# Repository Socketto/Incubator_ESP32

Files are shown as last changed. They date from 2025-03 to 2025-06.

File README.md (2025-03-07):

### Project Overview

This project was born out of the desire to see if supermarket quail eggs are actually fertile (unlike chicken eggs). The goal was to explore the possibility of incubating quail eggs and monitor their development.
  
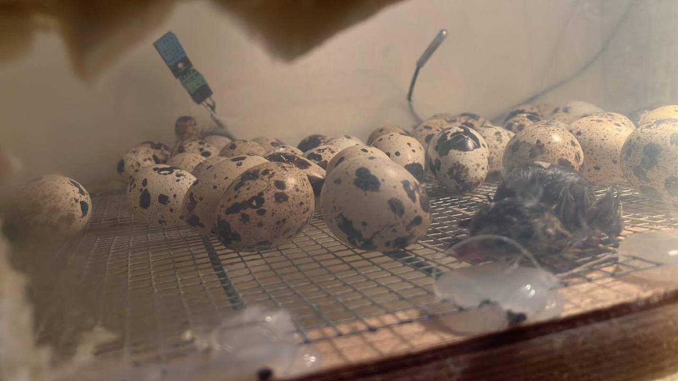
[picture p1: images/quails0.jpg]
quail
  

---

### The Incubator Design

To achieve this, I designed an **incubator for birds** using a thermally insulated plastic box. The setup is simple but effective for maintaining the right conditions for incubation.
  
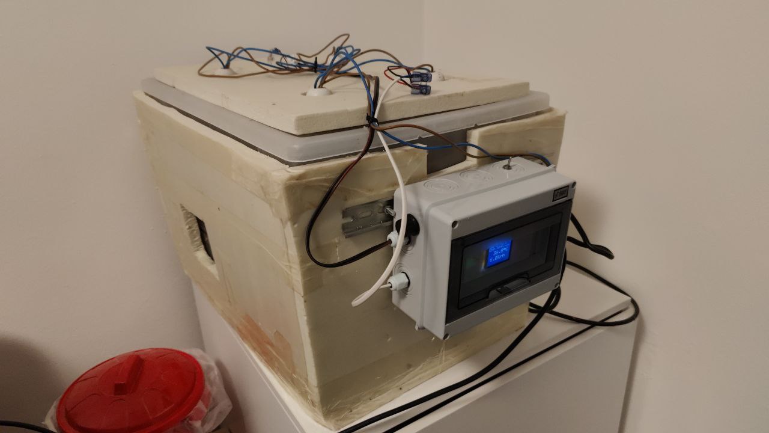
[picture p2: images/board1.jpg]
Incubator
  

---

### Temperature and Humidity Control

I managed the **temperature** and **humidity control** using a custom-designed board that features an **ESP32-WROOM** chip. This board was programmed using the **Arduino IDE**, providing full control over the incubator's conditions.

For heating, I used a **220V heater**, which I modulated using a **trimmer**. To maintain proper humidity inside, I used an **electric room humidifier**.

---

### User Interface and Remote Control

The board is equipped with a **color TFT graphical interface**, making it easy to monitor and control the incubator. Additionally, the incubator is controlled directly via a **Telegram bot** on your phone, allowing for remote management. 

For initial setup (WiFi credentials, Telegram token, and password), I added a feature that allows the board to switch to **Access Point (AP) mode**, enabling configuration through a minimal web server. These values are saved in the non-volatile memory of the ESP32, so they persist through future restarts.
  
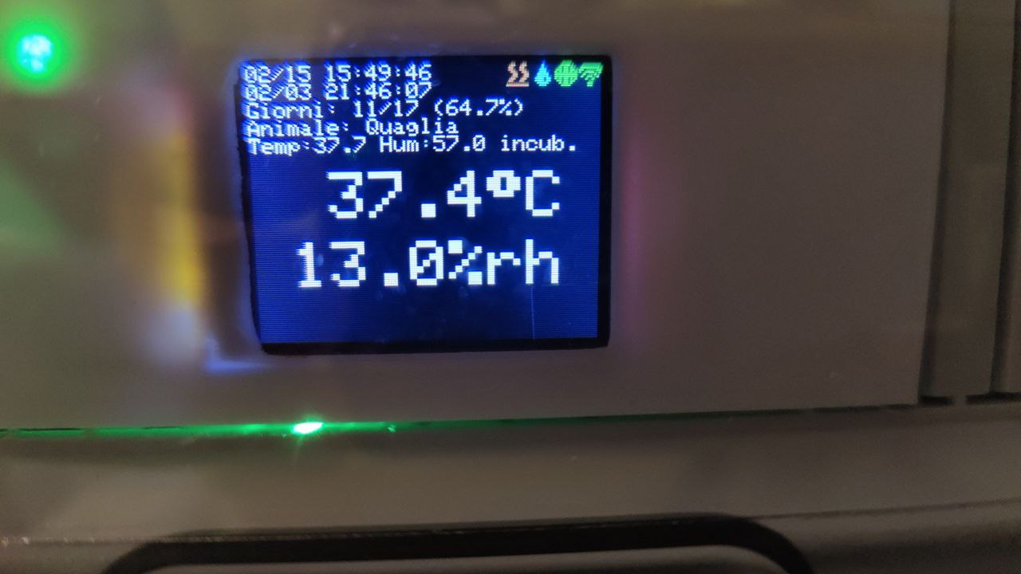
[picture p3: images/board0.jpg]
User interface
  

---

### Flexibility and Future Expansion

Currently, the software is configured to handle the **incubation periods**, **temperatures**, and **humidity** levels for chickens and quails. However, the system can easily be extended to accommodate other types of birds as well.
  
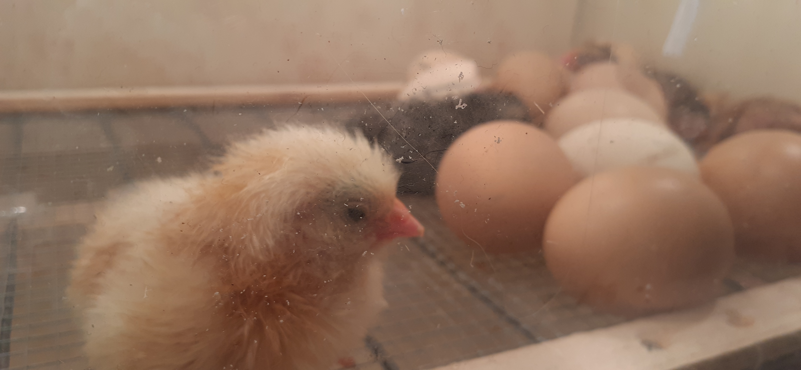
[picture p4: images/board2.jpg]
eggs
  

---

### Data Monitoring and Remote Supervision

The incubator's data can be communicated via **MQTT**, allowing for remote tracking of the incubation process from an external monitoring environment. I personally use **Node-RED** to monitor the data in real-time.

---

### Sharing the Experience

To make the project even more enjoyable, I set up a **live stream on Twitch** of the incubation process. This allows my friends to join in on the excitement and witness the first moments of life for the **❤️chicks❤️**.
  
[twitch channel](https://www.twitch.tv/socketto87)
  
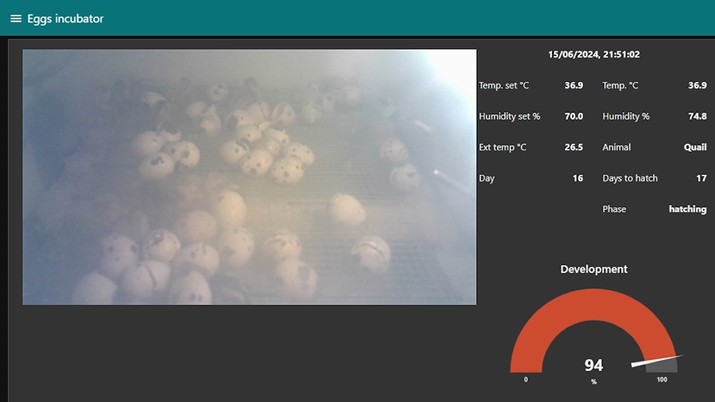
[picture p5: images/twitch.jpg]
twitch
  

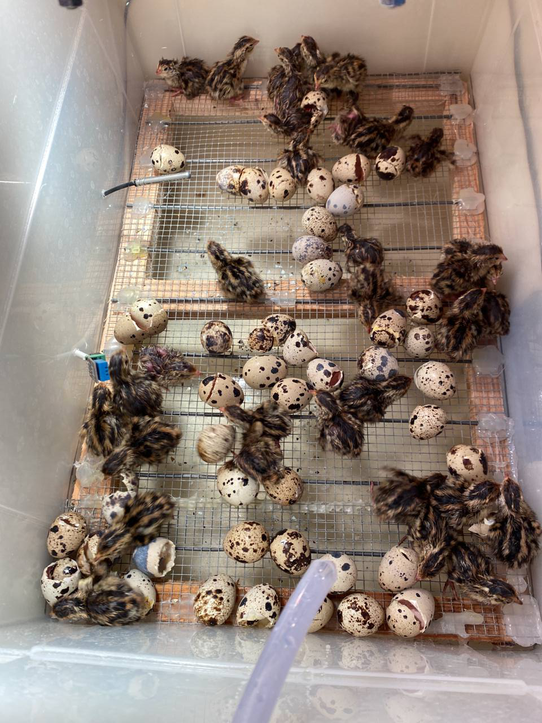
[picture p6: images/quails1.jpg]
quails


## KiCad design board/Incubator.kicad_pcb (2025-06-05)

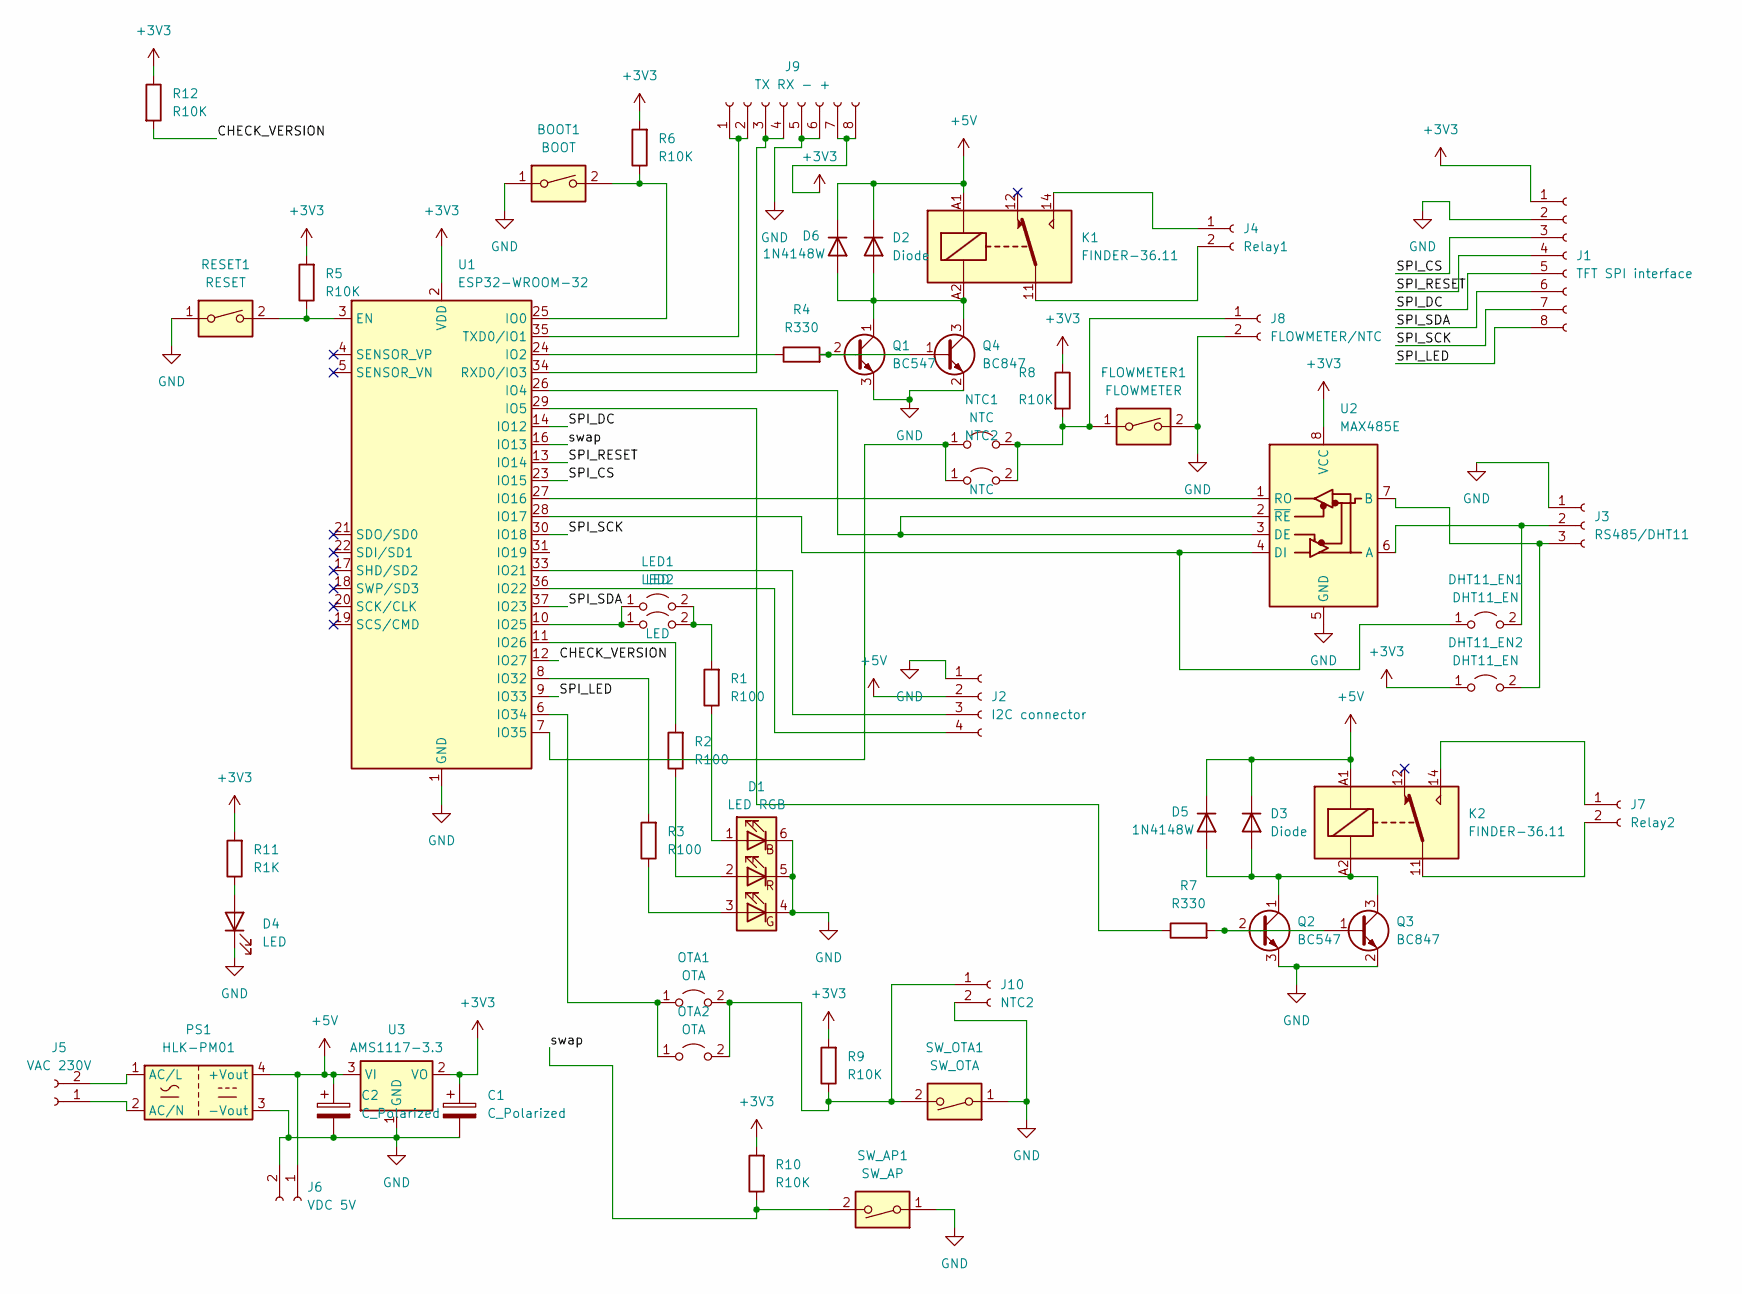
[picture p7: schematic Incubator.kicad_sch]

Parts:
BOOT1: BOOT; SW_PUSH_6mm_H4.3mm
C1, C2: C_Polarized; CP_Radial_D10.0mm_P5.00mm
D1: LED RGB; LED_RGB_5050-6
D2, D3: Diode; D_DO-35_SOD27_P10.16mm_Horizontal
D4: LED; LED_1206_3216Metric_Pad1.42x1.75mm_HandSolder
D5, D6: 1N4148W; D_SOD-123
DHT11_EN1, DHT11_EN2: DHT11_EN; SolderJumper-2_P1.3mm_Open_RoundedPad1.0x1.5mm
FLOWMETER1: FLOWMETER; SW_PUSH_6mm_H4.3mm
J1: TFT SPI interface; JST_XH_B8B-XH-AM_1x08_P2.50mm_Vertical
J2: I2C connector; JST_XH_B4B-XH-AM_1x04_P2.50mm_Vertical
J3: RS485/DHT11; PhoenixContact_MSTBA_2,5_3-G_1x03_P5.00mm_Horizontal
J4: Relay1; TerminalBlock_Altech_AK300-2_P5.00mm
J5: VAC 230V; TerminalBlock_Altech_AK300-2_P5.00mm
J6: VDC 5V; JST_XH_B2B-XH-A_1x02_P2.50mm_Vertical
J7: Relay2; TerminalBlock_Altech_AK300-2_P5.00mm
J8: FLOWMETER/NTC; TerminalBlock_Altech_AK300-2_P5.00mm
J9: TX RX - +; PinSocket_2x04_P2.54mm_Vertical
J10: NTC2; JST_XH_B2B-XH-A_1x02_P2.50mm_Vertical
K1, K2: FINDER-36.11; Relay_SPDT_Finder_36.11
LED1: LED; SolderJumper-2_P1.3mm_Open_RoundedPad1.0x1.5mm
LED2: LED; PinHeader_1x02_P2.54mm_Vertical
NTC1: NTC; PinHeader_1x02_P2.54mm_Vertical
NTC2: NTC; SolderJumper-2_P1.3mm_Open_RoundedPad1.0x1.5mm
OTA1: OTA; PinHeader_1x02_P2.54mm_Vertical
OTA2: OTA; SolderJumper-2_P1.3mm_Open_RoundedPad1.0x1.5mm
PS1: HLK-PM01; Converter_ACDC_HiLink_HLK-PMxx
Q1, Q2: BC547; TO-92_Inline
Q3, Q4: BC847; SOT-23
R1, R2, R3: R100; R_1206_3216Metric
R4, R7: R330; R_1206_3216Metric
R5, R6, R8, R9, R10, R12: R10K; R_1206_3216Metric
R11: R1K; R_1206_3216Metric
RESET1: RESET; SW_PUSH_6mm_H4.3mm
SW_AP1: SW_AP; SW_PUSH_6mm_H4.3mm
SW_OTA1: SW_OTA; SW_PUSH_6mm_H4.3mm
U1: ESP32-WROOM-32
U2: MAX485E; SO-8_3.9x4.9mm_P1.27mm
U3: AMS1117-3.3; SOT-223-3_TabPin2

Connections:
+3V3: C1.1, DHT11_EN2.1 (A), J1.1, J9.7, J9.8, R5.2, R6.2, R8.1, R9.2, R10.2, R11.2, R12.1, U1.2 (VDD), U2.8 (VCC), U3.2 (VO)
+5V: C2.1, D2.1 (K), D3.1 (K), D5.1 (K), D6.1 (K), J2.2, J6.1, K1.A1, K2.A1, PS1.4 (+Vout), U3.3 (VI)
/CHECK_VERSION: R12.2, U1.12 (IO27)
/SPI_CS: J1.3, U1.23 (IO15)
/SPI_DC: J1.5, U1.14 (IO12)
/SPI_LED: J1.8, U1.9 (IO33)
/SPI_RESET: J1.4, U1.13 (IO14)
/SPI_SCK: J1.7, U1.30 (IO18)
/SPI_SDA: J1.6, U1.37 (IO23)
/swap: R10.1, SW_AP1.2, U1.16 (IO13)
GND: BOOT1.1, C1.2, C2.2, D1.4 (GK), D1.5 (RK), D1.6 (BK), D4.1 (K), FLOWMETER1.2, J1.2, J2.1, J3.1, J6.2, J8.2, J9.5, J9.6, J10.2, PS1.3 (-Vout), Q1.3 (E), Q2.3 (E), Q3.2 (E), Q4.2 (E), RESET1.1, SW_AP1.1, SW_OTA1.1, U1.1 (GND), U1.15 (GND), U1.38 (GND), U1.39 (GND), U2.5 (GND), U3.1 (GND)
unnamed: D1.1 (BA), R1.1
unnamed: D1.3 (GA), R3.1
unnamed: D1.2 (RA), R2.1
unnamed: D2.2 (A), D6.2 (A), K1.A2, Q1.1 (C), Q4.3 (C)
unnamed: D3.2 (A), D5.2 (A), K2.A2, Q2.1 (C), Q3.3 (C)
unnamed: D4.2 (A), R11.1
unnamed: DHT11_EN1.1 (A), U1.28 (IO17), U2.4 (DI)
unnamed: DHT11_EN1.2 (B), J3.2, U2.6 (A)
unnamed: DHT11_EN2.2 (B), J3.3, U2.7 (B)
unnamed: J2.3, U1.33 (IO21)
unnamed: J2.4, U1.36 (IO22)
unnamed: J4.1, K1.14
unnamed: J4.2, K1.11
unnamed: J5.1, PS1.2 (AC/N)
unnamed: J5.2, PS1.1 (AC/L)
unnamed: J7.1, K2.14
unnamed: J7.2, K2.11
unnamed: FLOWMETER1.1, J8.1, NTC1.2 (B), NTC2.2 (B), R8.2
unnamed: J9.1, J9.2, U1.35 (TXD0/IO1)
unnamed: J9.3, J9.4, U1.34 (RXD0/IO3)
unnamed: J10.1, OTA1.2 (B), OTA2.2 (B), R9.1, SW_OTA1.2
unnamed: LED1.1 (A), LED2.1 (A), U1.10 (IO25)
unnamed: LED1.2 (B), LED2.2 (B), R1.2
unnamed: NTC1.1 (A), NTC2.1 (A), U1.7 (IO35)
unnamed: OTA1.1 (A), OTA2.1 (A), U1.6 (IO34)
unnamed: Q1.2 (B), Q4.1 (B), R4.2
unnamed: Q2.2 (B), Q3.1 (B), R7.2
unnamed: R5.1, RESET1.2, U1.3 (EN)
unnamed: BOOT1.2, R6.1, U1.25 (IO0)
unnamed: R4.1, U1.24 (IO2)
unnamed: U1.26 (IO4), U2.2 (~RE), U2.3 (DE)
unnamed: R7.1, U1.29 (IO5)
unnamed: U1.27 (IO16), U2.1 (RO)
unnamed: R2.2, U1.11 (IO26)
unnamed: R3.2, U1.8 (IO32)

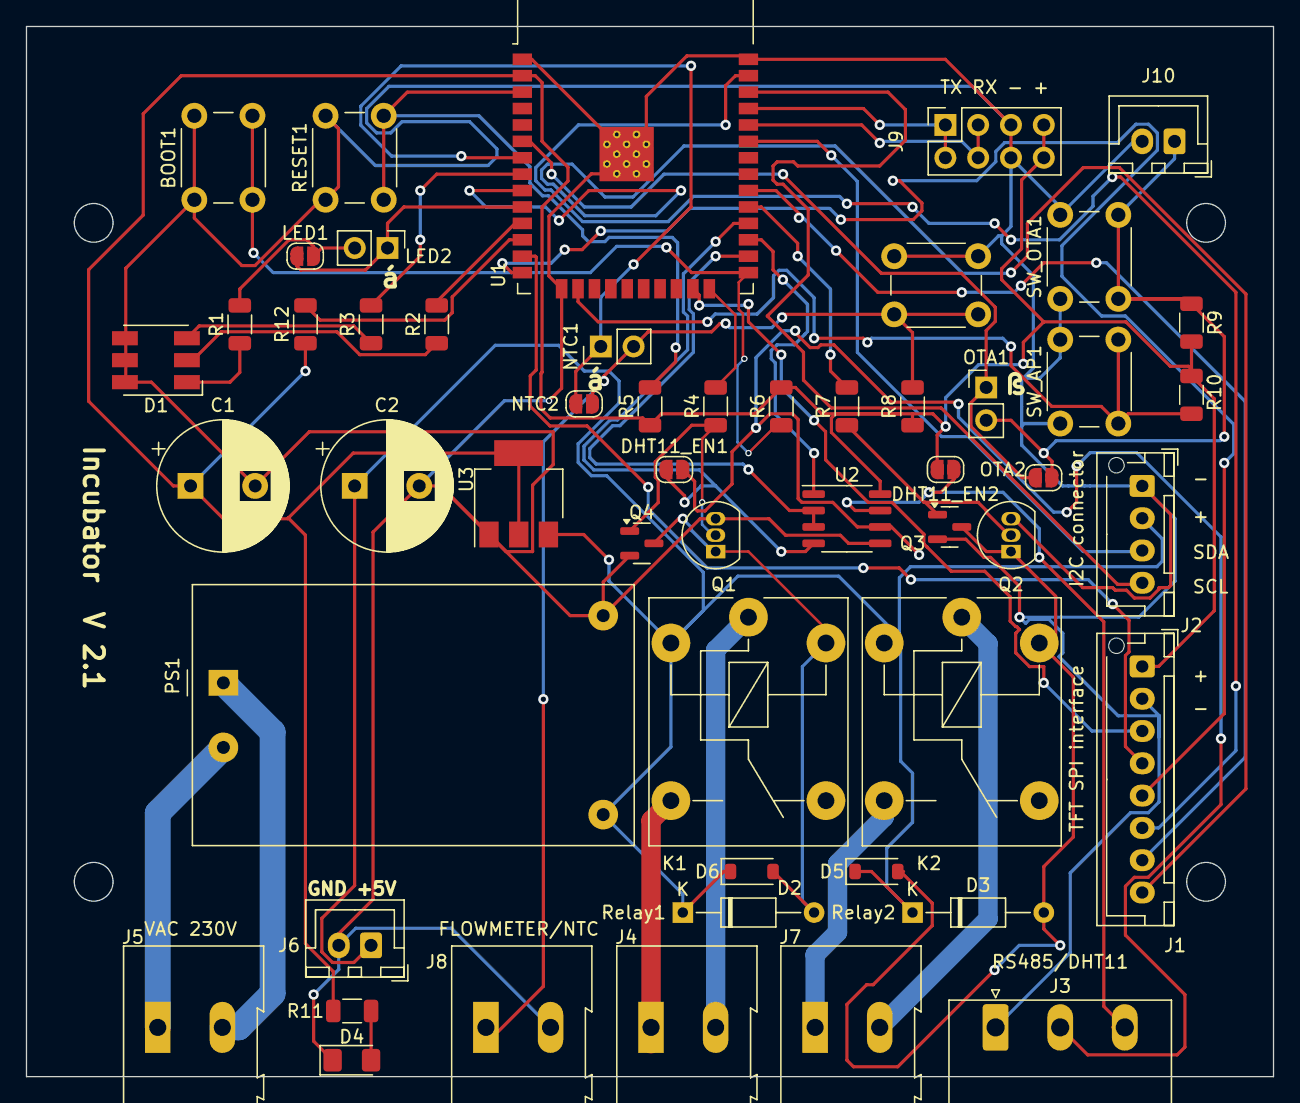
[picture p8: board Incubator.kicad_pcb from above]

Board: 2 copper layers, 96.5 x 81.3 mm, 53 parts (0 on the bottom side), 46 nets.

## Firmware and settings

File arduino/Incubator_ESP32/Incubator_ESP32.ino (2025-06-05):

#include <WiFi.h>
#include <Preferences.h>
#define NTC_SAMPLES 30

volatile int cycleTime = 10000; // 10 secondi
volatile int minOnTime = 3000;  // 2 secondi
volatile int customminOnTime = 0;
volatile int maxOnTime = 9000;  // 9 secondi

volatile double deltasetpoint = 0;
volatile double deltaTemperature = 0;
volatile long TimeUpdateMQTT = 60000;

bool DebugMutex = false;

SemaphoreHandle_t xMutex;  // Mutex per proteggere l'accesso
String ssid;
String ssidpassword;
String BOTtoken;
String AdminTelegram;
char stringWifi[200];
bool APMode = false;
char ChipID[50];

const char* WIFI_NAME = "WIFI_NAME";
const char* WIFI_PASSWORD = "WIFI_PASSWORD";
const char* TELEGRAM_BOT = "TELEGRAM_BOT";
const char* TELEGRAM_ADMIN = "TELEGRAM_ADMIN";
const char* URL_MQTT = "URL_MQTT";
const char* USERNAME_MQTT = "USERNAME_MQTT";
const char* PASSWORD_MQTT = "PASSWORD_MQTT";

int waitTemp = 0;
volatile int RebootRequested = -1;
int autoresetDisplay = 360;
int lastCheckReboot;
int animaleint = 0;
char Animale[200];


char StartIncubata[200];

bool AlarmsManagement = true;
int StepIncubata = 0;
int giornipassatiint = 0;
int giornipassatiintold = 0;
int giornitotaliint = 0;
char GiorniPassati[200];
char humstr[200];

char StartDay[200];
char settingsstr[200];
unsigned long lastreadntc;
char lcdStringTemp1[200];
char lcdStringTemp2[200];
int SecondsSetupWifi = 30;
bool first_read_time = true;
bool ErrorHumidity = true;
double Arraytemp[NTC_SAMPLES];
int indexarratemp = 0;
bool Temp1Ready = false;

float desiredH = 70;
double tempext = 0, tempextt = 0, desiredT = 37.0;
double histT = 0.1, histH = 10;

bool Reset = false;
Preferences preferences;
Preferences preferences_command;

volatile float humidity;
unsigned long lastCheckLocalTime = 0;
unsigned long lastTemperatureMQTT = 0;
unsigned long lastCheckAlarms = 0;
unsigned int testpercentage = 0;
long mainLightsForce = 0;
struct tm timeinfo;
struct tm startTime;
bool heater = false, humidifier = false;

const char* ntpServer = "pool.ntp.org";
const long gmtOffset_sec = 3600;
const int daylightOffset_sec = 3600;
// Latitude and Longitude for Piove di Sacco, Italy
float latitude = 45.2991;
float longitude = 12.0468;
float PercentageGiorniPassati = 0;

// Function to check if Daylight Saving Time (DST) is in effect
bool isDST(int day, int month, int dow) {
  if (month < 3 || month > 10) return false;
  if (month > 3 && month < 10) return true;

  int previousSunday = day - dow;

  if (month == 3) return previousSunday >= 25;
  if (month == 10) return previousSunday < 25;

  return false;
}

void StartAPMode() {
  Cian(true);
  delay(2000);
  WiFi.mode(WIFI_AP);
  sprintf(stringWifi, "%s", ChipID);
  WiFi.softAP(stringWifi, "12345679");
  sprintf(lcdStringTemp2, "%s", ChipID);
  TFT_log("WIFI", lcdStringTemp2, 3);
  TFT_log("PASSWORD", "12345679", 3);
  delay(5000);
  APMode = true;
  preferences.putUInt("APMode", 0);
  setupAP();
}

void saveTimeInfo() {
  preferences.begin("time-info", false);
  preferences.putInt("tm_sec", timeinfo.tm_sec);
  preferences.putInt("tm_min", timeinfo.tm_min);
  preferences.putInt("tm_hour", timeinfo.tm_hour);
  preferences.putInt("tm_mday", timeinfo.tm_mday);
  preferences.putInt("tm_mon", timeinfo.tm_mon);
  preferences.putInt("tm_year", timeinfo.tm_year);
  preferences.putInt("tm_wday", timeinfo.tm_wday);
  preferences.putInt("tm_yday", timeinfo.tm_yday);
  preferences.putInt("tm_isdst", timeinfo.tm_isdst);
  preferences.end();
}
void readTimeInfo() {
  preferences.begin("time-info", true);
  startTime.tm_sec = preferences.getInt("tm_sec", 0);
  startTime.tm_min = preferences.getInt("tm_min", 0);
  startTime.tm_hour = preferences.getInt("tm_hour", 0);
  startTime.tm_mday = preferences.getInt("tm_mday", 1);
  startTime.tm_mon = preferences.getInt("tm_mon", 0);
  startTime.tm_year = preferences.getInt("tm_year", 70);
  startTime.tm_wday = preferences.getInt("tm_wday", 0);
  startTime.tm_yday = preferences.getInt("tm_yday", 0);
  startTime.tm_isdst = preferences.getInt("tm_isdst", -1);
  preferences.end();
}

void CheckLocalTime() {
  if (!getLocalTime(&timeinfo)) {
    TFT_log("Time", "Failed to obtain time", 2);
    Serial.println("Failed to obtain time");
    Red(true);
    return;
  } else {
    strftime(lcdStringTemp1, sizeof(lcdStringTemp1), "%m/%d %H:%M:%S", &timeinfo);
    if (Reset) {
      saveTimeInfo();
      Reset = false;
    }

    readTimeInfo();
    strftime(StartDay, sizeof(StartDay), "%m/%d %H:%M:%S", &startTime);

    if (first_read_time) {
      first_read_time = false;
      TFT_log("Time", lcdStringTemp1, 0);
    }

    UpdateTime(lcdStringTemp1);
  }
  //Serial.println(&timeinfo, "%A, %B %d %Y %H:%M:%S");
}


void setup() {
  Serial.begin(115200);
  xMutex = xSemaphoreCreateMutex();  // Creazione del mutex
  strcpy(ChipID, Network.macAddress().c_str());
  
  struct tm timeInfo;
  if(preferences_command.begin("incu1"))
  {
    animaleint = preferences_command.getInt("Animale", 0);
    if (animaleint == 2) {
      AlarmsManagement = false;
    }

    deltaTemperature = (double)preferences_command.getInt("deltaTe", 0.0)/100;
    Serial.println(deltaTemperature);
    deltasetpoint = (double)preferences_command.getInt("deltase", 0)/100;
    Serial.println(deltasetpoint);
    TimeUpdateMQTT = preferences_command.getLong("TimQTT", 60000);
    Serial.println(TimeUpdateMQTT);
    maxOnTime = preferences_command.getInt("maxOnTime", 9000);
    Serial.println(maxOnTime);
    minOnTime = preferences_command.getInt("minOnTime", 3000);
    Serial.println(minOnTime);
    cycleTime = preferences_command.getInt("cycleTime", 10000);
    Serial.println(cycleTime);
    desiredT = preferences_command.getFloat("desiredT", 37);
    Serial.println(desiredT);
    desiredH = preferences_command.getFloat("desiredH", 70);
    Serial.println(desiredH);
    customminOnTime = preferences_command.getInt("customm", 0);
    Serial.println(customminOnTime);
    preferences_command.end();
  }
  else
  {
    Serial.println("ERROR (preferences_command.begin)");
  }
  initHeaterTask();
  Serial.println("setupIO()");
  setupIO();
  Yellow(false);
  delay(200);
  Serial.println("SetupTFT()");
  SetupTFT();
  TFT_log_init();
  Serial.println("TFT_log_init");
  delay(200);
  WiFi.mode(WIFI_STA);
  Serial.println("WiFi.mode(WIFI_STA)");
  preferences.begin("my-app", true);
  ssid = preferences.getString("SSID", "");
  ssidpassword = preferences.getString("SSIDPSW", "");
    if (ssid == "" || ssidpassword == "") {
      TFT_log("ERROR WIFI", "NOT SETTED!", 2);
      ssid = "TEST";
      ssidpassword = "123456789";
      SecondsSetupWifi = 0;
      delay(5000);
    }
  WiFi.begin(ssid, ssidpassword);
  Serial.print("Connecting to WiFi: ");
  ssid.toCharArray(stringWifi, ssid.length() + 1);
  TFT_log("WIFI", stringWifi, 1);
  TFT_log_append("WAIT seconds ", 30, true);
  Serial.println(ssid);
  Red(true);
  while (WiFi.status() != WL_CONNECTED && SecondsSetupWifi > 0) {
    Serial.print('.');
    TFT_log_append(".", 65535, false);
    SecondsSetupWifi--;
    delay(1000);
  }
  if(SecondsSetupWifi == 0)
  {
    StartAPMode();
    return;
  }
  else
  {
    setupAP();
  }
  BOTtoken = preferences.getString("TELEGRAM_BOT", "");
  Serial.println(BOTtoken);
  AdminTelegram = preferences.getString("TELEGRAM_ADMIN", "");
  Serial.println(AdminTelegram);
  preferences.end();
  Green(true);
  Serial.println("TelegramSetup()");
  TelegramSetup();
  delay(200);
  MQTT_setServer();
  while (MQTT_reconnect() == false) {
    delay(1000);
  }
  //init and get the time
  configTime(gmtOffset_sec, daylightOffset_sec, ntpServer);
  CheckLocalTime();
  InitDashboard();
  Serial.println("TimeTask...");
  xTaskCreate(
    TelegramTask,   /* Task function. */
    "TelegramTask", /* String with name of task. */
    20000,          /* Stack size in bytes. */
    NULL,           /* Parameter passed as input of the task */
    0,              /* Priority of the task. */
    NULL);          /* Task handle. */

  setupDHT();
}

void TelegramTask(void* pvParameters) {
  while (true) {
    TelegramLoop();
    vTaskDelay(pdMS_TO_TICKS(200));  // Usa FreeRTOS per ritardare il task
  }
}

tm copyTMStruct(tm* source) {
  tm destination;
  destination.tm_sec = source->tm_sec;
  destination.tm_min = source->tm_min;
  destination.tm_hour = source->tm_hour;
  destination.tm_mday = source->tm_mday;
  destination.tm_mon = source->tm_mon;
  destination.tm_year = source->tm_year;
  destination.tm_wday = source->tm_wday;
  destination.tm_yday = source->tm_yday;
  destination.tm_isdst = source->tm_isdst;

  return destination;
}
// Funzione per convertire una struttura tm in epoch time
time_t tmToEpochTime(tm& date) {
  tm tempdatetime = copyTMStruct(&date);
  return mktime(&tempdatetime);
}

// Funzione per calcolare la differenza in giorni tra due date
int differenceInDays(tm& startDate, tm& endDate) {
  time_t startEpoch = tmToEpochTime(startDate);
  time_t endEpoch = tmToEpochTime(endDate);
  double differenceInSeconds = difftime(endEpoch, startEpoch);
  int differenceInDaysi = (int)(differenceInSeconds / (60 * 60 * 24));
  return differenceInDaysi;
}

void loop() {

  if(APMode)
  {
    checkAP();
    return;
  }
  else
  {
    checkAP();
  }

  if (millis() > lastCheckReboot + 1000) {  //1 minuto
    lastCheckReboot = millis();
    if (xSemaphoreTake(xMutex, portMAX_DELAY)) {
      if (DebugMutex) {
        Serial.println("Mutex RebootRequested");
      }
      if (RebootRequested >= 0) {
        RebootRequested--;
      }
      if (RebootRequested == 0) {
        ESP.restart();
      }
      if (DebugMutex) {
        Serial.println("Mutex released");
      } 

      xSemaphoreGive(xMutex);
    }
  }



  if (WiFi.status() != WL_CONNECTED) {
    UpdateWifiStatus(0);
    UpdateServerStatus(0);
    Red(true);
    if (WiFi.status() != WL_CONNECTED) {
      Serial.print('.');
      TFT_log_append(".", 65535, false);
      delay(1000);
      SecondsSetupWifi--;
      if (SecondsSetupWifi <= 0) {
        SecondsSetupWifi = 30;
        WiFi.disconnect();
        WiFi.reconnect();
      }
    }
    TFT_log_append("", 65535, true);
  } else {
    UpdateWifiStatus(2);
    Green(true);
    if (MQTT_reconnect()) {
      MQTT_loop();
	  if (xSemaphoreTake(xMutex, portMAX_DELAY)) {   
		if (DebugMutex) {
		  Serial.println("Mutex MQTT_Wifi_Status");
		}
		MQTT_Wifi_Status(WiFi.RSSI());
		xSemaphoreGive(xMutex); 
		if (DebugMutex) {
		  Serial.println("Mutex released");
		}
	  }
    }
  }

  if (xSemaphoreTake(xMutex, portMAX_DELAY)) {
    if (DebugMutex) {
      Serial.println("Mutex loop");
    }
    switch (animaleint) {
      case 0:
        giornitotaliint = 21;
        strcpy(Animale, "Animale: Gallina");
        if (giornipassatiint <= 18) {
          StepIncubata = 1;
        } else {
          if (StepIncubata < 2)
            StepIncubata = 2;
        }
        break;
      case 1:
        giornitotaliint = 17;
        strcpy(Animale, "Animale: Quaglia");
        if (giornipassatiint <= 15) {
          StepIncubata = 1;
        } else {
          if (StepIncubata < 2)
            StepIncubata = 2;
        }
        break;
      case 2:
        giornitotaliint = 365;
        strcpy(Animale, "Animale: NO");
        StepIncubata = 100;
        break;
    }
    switch (StepIncubata) {
      case 1:  //incubazione
        desiredH = 57;
        desiredT = 37.7;
        histT = 0.1;
        histH = 10;
        sprintf(settingsstr, "Temp:%2.1f Hum:%2.1f incub.", desiredT, desiredH);
        break;
      case 2:  //schiusa
        desiredH = 70;
        desiredT = 36.9;
        histT = 0.1;
        histH = 10;
        sendSchiusa();
        StepIncubata = 3;
        break;
      case 3:  //schiusa
        sprintf(settingsstr, "Temp:%2.1f Hum:%2.1f schiusa", desiredT, desiredH);
        break;
      default:
        sprintf(settingsstr, "Temp:%2.1f Hum:%2.1f ----", desiredT, desiredH);
        break;
    }

    giornipassatiint = differenceInDays(startTime, timeinfo);

    PercentageGiorniPassati = (float)((float)(giornipassatiint * 100) / (float)(giornitotaliint));
    sprintf(GiorniPassati, "Giorni: %d/%d (%2.1f%%)", giornipassatiint, giornitotaliint, PercentageGiorniPassati);

    if (millis() > lastTemperatureMQTT + TimeUpdateMQTT) {  //60 sec
      lastTemperatureMQTT = millis();
      MQTT_Publish();
      if(autoresetDisplay > 0) //
      {
        autoresetDisplay--;
        if(autoresetDisplay == 0)
        {
          autoresetDisplay = 30; //30 mim
          ResetTFT();
        }
      }
      if(customminOnTime == 0)
      {
          if(readtempEXT() <= 15)
          {
            minOnTime = 4000;
          }
          if(readtempEXT() > 15)
          {
            minOnTime = 3000;
          }
          if(readtempEXT() > 20)
          {
            minOnTime = 2000;
          }
          if(readtempEXT() > 25)
          {
            minOnTime = 1000;
          }
      }
    }

    if (millis() > lastreadntc + 100) {
      lastreadntc = millis();
      Arraytemp[indexarratemp] = readtemp();
      indexarratemp++;
      if (indexarratemp >= NTC_SAMPLES) {
        indexarratemp = 0;
        Temp1Ready = true;
      } else {
        waitTemp = (int)((double)((double)indexarratemp / (double)NTC_SAMPLES) * 100);
      }
      if (Temp1Ready) {
        tempextt = 0;
        for (int o = 0; o < NTC_SAMPLES; o++) {
          tempextt = tempextt + Arraytemp[o];
        }
        tempext = tempextt / NTC_SAMPLES;
      }
    }
    Updaterows();
    /*if (Temp1Ready) {
      if (tempext > desiredT + histT)
        heater = false;
      if (tempext < desiredT - histT)
        heater = true;
    }*/
    humidity = loopDHT();
    if (humidity >= 0) {
      ErrorHumidity = false;
      sprintf(humstr, " %2.1f%%rh", humidity);
      if (humidity > desiredH + histH)
        humidifier = false;
      if (humidity < desiredH - histH)
        humidifier = true;
    } else {
      ErrorHumidity = true;
    }
    CheckLocalTime();
    //Relay1(heater);
    Relay2(humidifier);
    if (DebugMutex) {
      Serial.println("Mutex released");
    }
    xSemaphoreGive(xMutex);
  }
}

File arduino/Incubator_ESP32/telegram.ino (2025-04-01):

#include <WiFiClientSecure.h>
#include <UniversalTelegramBot.h>  // Universal Telegram Bot Library written by Brian Lough: https://github.com/witnessmenow/Universal-Arduino-Telegram-Bot
#include <ArduinoJson.h>
#include <Preferences.h>
#include <HTTPClient.h>
#include <WiFi.h>

UniversalTelegramBot* bot;  // Pointer declaration
// Initialize Telegram BOT
char MessageAuthomatic[400];

bool userAuthorized(String value) {
  if (AdminTelegram == value) {
    return true;  // value found
  }
  return false;  // value not found
}


float extractFloat(String input) {
  bool foundDigit = false;
  String numStr = "";

  for (int i = 0; i < input.length(); i++) {
    char c = input[i];


    if (isdigit(c) || c == '.') {
      numStr += c;
      foundDigit = true;
    }

    else if (c == '-' && !foundDigit && i + 1 < input.length() && isdigit(input[i + 1])) {
      numStr += c;
    }

    else if (foundDigit) {
      break;
    }
  }

  return numStr.length() > 0 ? numStr.toFloat() : 0.0;
}

char messaget[400];
WiFiClientSecure clientt;

// Checks for new messages every 1 second.
int botRequestDelay = 1000;
unsigned long lastTimeBotRan;


// Handle what happens when you receive new messages
void handleNewMessages(int numNewMessages) {
  Serial.println("handleNewMessages");
  Serial.println(String(numNewMessages));

  for (int i = 0; i < numNewMessages; i++) {
    // Chat id of the requester
    String chat_id = String(bot->messages[i].chat_id);
    if (userAuthorized(chat_id) == false) {
      bot->sendMessage(chat_id, "Unauthorized user", "");
      continue;
    }

    // Print the received message
    String text = bot->messages[i].text;
    Serial.println(text);

    String from_name = bot->messages[i].from_name;

    if (text == "/start") {
      String welcome = "Welcome";
      bot->sendMessage(chat_id, welcome, "");
    }

    if (text == "/status") {
      if (Temp1Ready) {
        sprintf(messaget, "Wifi signal: %d%%\n%s\n%s\nTemperature: %2.1f°C\nHumidity: %2.1f%%\nStart: %s\nIP: http://%s", testpercentage, Animale, GiorniPassati, tempext, humidity, StartIncubata, WiFi.localIP().toString());
        bot->sendMessage(chat_id, messaget, "");
        sprintf(messaget, "cycle-time %i\nmin-on-time %i\ncustomminOnTime %i\nmax-on-time %i\nset-delta-set-point %2.2f\nupdate-mqtt %lu\nset-delta-temp %2.2f", cycleTime, minOnTime, customminOnTime, maxOnTime, deltasetpoint, TimeUpdateMQTT, deltaTemperature);
        bot->sendMessage(chat_id, messaget, "");
        MQTT_Publish();
      } else {
        sprintf(messaget, "Wifi signal: %d%%", testpercentage);
        bot->sendMessage(chat_id, messaget, "");
      }
    }

    if (text == "/gallina") {
      preferences_command.begin("incu1", false);
      preferences_command.putInt("Animale", 0);
      animaleint = 0;
      preferences_command.end();
      bot->sendMessage(chat_id, "Ok", "");
      AlarmsManagement = true;
    }

    if (text == "/quaglia") {
      preferences_command.begin("incu1", false);
      preferences_command.putInt("Animale", 1);
      animaleint = 1;
      preferences_command.end();
      bot->sendMessage(chat_id, "Ok", "");
      AlarmsManagement = true;
    }

    if (text == "/noanimal") {
      preferences_command.begin("incu1", false);
      preferences_command.putInt("Animale", 2);
      animaleint = 2;
      preferences_command.end();
      bot->sendMessage(chat_id, "Ok", "");
      AlarmsManagement = false;
    }

    if (text == "reset-display") {
      ResetTFT();
      bot->sendMessage(chat_id, "Ok", "");
    }

    if (text == "soft-reset-tft") {
      SoftResetTFT();
      bot->sendMessage(chat_id, "Ok", "");
    }


    if (text == "/reset") {
      Reset = true;
      bot->sendMessage(chat_id, "Ok", "");
    }

    if (text == "/reboot") {
      bot->sendMessage(chat_id, "Ok", "");
      RebootRequested = 7;
    }

    if (text == "comandi") {
      bot->sendMessage(chat_id, "reset-display\nsoft-reset-tft\nset-temp 60\ncycle-time 10000\nmin-on-time 3000\ndefault-min-on-time\nmax-on-time 9000\nupdate-mqtt 60000\nset-delta-set-point 1.5\nset-delta-temp 1.5\nset-hum 50", "");
    }

    if (text.startsWith("set-temp ")) {
      desiredT = extractFloat(text);
      preferences_command.begin("incu1", false);
      preferences_command.putFloat("desiredT", desiredT);
      preferences_command.end();
      bot->sendMessage(chat_id, "Ok", "");
    }
    if (text.startsWith("cycle-time ")) {
      cycleTime = (int)extractFloat(text);
      preferences_command.begin("incu1", false);
      preferences_command.putInt("cycleTime", cycleTime);
      preferences_command.end();
      bot->sendMessage(chat_id, "Ok", "");
    }
    if (text.startsWith("min-on-time ")) {
      minOnTime = (int)extractFloat(text);
      preferences_command.begin("incu1", false);
      preferences_command.putInt("minOnTime", minOnTime);
      preferences_command.end();
      customminOnTime = minOnTime;
      preferences_command.begin("incu1", false);
      preferences_command.putInt("customminOnTime", customminOnTime);
      preferences_command.end();
      bot->sendMessage(chat_id, "Ok", "");
    }
    if (text == "default-min-on-time") {
      customminOnTime = 0;
      preferences_command.begin("incu1", false);
      preferences_command.putInt("customm", customminOnTime);
      preferences_command.end();
      bot->sendMessage(chat_id, "Ok", "");
    }
    if (text.startsWith("max-on-time ")) {
      maxOnTime = (int)extractFloat(text);
      preferences_command.begin("incu1", false);
      preferences_command.putInt("maxOnTime", maxOnTime);
      preferences_command.end();
      bot->sendMessage(chat_id, "Ok", "");
    }
    if (text.startsWith("update-mqtt ")) {
      TimeUpdateMQTT = (long)extractFloat(text);
      preferences_command.begin("incu1", false);
      preferences_command.putLong("TimQTT", TimeUpdateMQTT);
      preferences_command.end();
      bot->sendMessage(chat_id, "Ok", "");
    }
    if (text.startsWith("set-delta-set-point ")) {
      deltasetpoint = extractFloat(text);
      preferences_command.begin("incu1", false);
      preferences_command.putInt("deltase", (int)(deltasetpoint * 100));
      preferences_command.end();
      bot->sendMessage(chat_id, "Ok", "");
    }
    if (text.startsWith("set-delta-temp ")) {
      deltaTemperature = extractFloat(text);
      preferences_command.begin("incu1", false);
      preferences_command.putInt("deltaTe", (int)(deltaTemperature * 100));
      preferences_command.end();
      bot->sendMessage(chat_id, "Ok", "");
    }



    if (text.startsWith("set-hum ")) {
      desiredH = extractFloat(text);
      preferences_command.begin("incu1", false);
      preferences_command.putFloat("desiredH", desiredH);
      preferences_command.end();
      bot->sendMessage(chat_id, "Ok", "");
    }
  }
}


int sendSchiusaFlag = 0;
void sendSchiusa() {
  sendSchiusaFlag = 1;
}
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

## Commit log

2025-03-24 [ADD] Add first draft to change ON OFF of heater dinamically
2025-03-25 [ENH] Enhance management of temperature
2025-03-26 [UPD] Save value on preferences to set the incubator temperature regulation
2025-03-27 [ADD] Add command and use another Preferences for temperature modulation
2025-04-01 [FIX] Fix some issue on management of messages of Telegram and add check on preferences_command.begin("incu1") at start
    [Incubator_ESP32.ino, telegram.ino]
2025-04-18 [UPD] Update board
    [Incubator.kicad_pcb, Incubator.kicad_sch]
2025-06-05 [UPD] Update days and avoid wire interferences
    [Incubator.kicad_pcb, Incubator.kicad_sch]
